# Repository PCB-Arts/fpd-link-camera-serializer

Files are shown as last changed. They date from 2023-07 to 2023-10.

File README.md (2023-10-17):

# fpd-link-camera-serializer
CSI to FDP link serializer board based on the Texas instruments DS90UB953 up to 2.3MP/60fps. Power over coax implementation at 24V cable supply. The board has different I2C sensors to interface with over the I2C - FPD Link Channel. The different sensors are described in the I2C-Sensor section 

## I2C Sensors

### Accelerometer (0x19)
There is a 6-axis Motion Tracking IC installed on the fpd-link-camera-serializer (BMI088). It's purpose is to detecting vibrations or motions. 
Datasheet: https://www.bosch-sensortec.com/media/boschsensortec/downloads/datasheets/bst-bmi088-ds001.pdf

### Gyroscope (0x68)
It's the same BMI088 Chip. 

### Temperature Sensor (0x48) 
There is also a Temperature sensor (TMP1075) installed for detecting envioronment paramenters, which could affect the camera sensor. 
Datasheet: https://www.ti.com/lit/ds/symlink/tmp1075.pdf

### PCA9685 (0x40) 
For interacting with LEDs, for generating local light on the camera side, there is a LED Controller installed (PCA9685). 
Datasheet: https://www.nxp.com/docs/en/data-sheet/PCA9685.pdf

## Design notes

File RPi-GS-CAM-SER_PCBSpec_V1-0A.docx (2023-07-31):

# Document History

Revision | Date / Datum | Short mark | Concerned clause / Betr. Abschnitt | Reason of modification / Grund der Änderung
A | 2023-05-29 | MW | All | First Version

Product: Produkt: | RPi-GS-CAM-SER | Version: | 1.0

Size / Format: | Base dimensions / Grundmass: 38.0 mm x 38.0 mm Tolerances / Toleranzen: Width / Breite 38.0 ± 0.2 mm Length / Länge 38.0 ± 0.2 mm
Thickness / Dicke: | Tolerance / Toleranz: 1.6 mm ± 0.16 mm
Number of layers / Anzahl der Lagen: | 4, plated-through / durchkontaktiert

Build-up of layers / Lagenaufbau: | Material: FR4, UL 94-V0, Gruppe IIIa, 130°C see Build-up of layers (End of Document) siehe Lagenaufbau (Ende des Dokuments)

Number of holes (total) / Anzahl der Bohrungen (gesamt): | 484 (incl. 465 Vias)
Minimum plated through hole diameter / Kleinster Enddurchmesser: | 0.2 mm
Finished plated hole tolerance (deviant from standard) / Bohrtoleranz (abweichend vom Standard): | n/a
Non plated through holes (NDK) / Nicht durchkontaktierte Bohrungen (NDK): | Yes / Ja
SMD: | Double-sided / zweiseitig
Smallest conductor width / Kleinste Leiterbahnbreite: | 0.127 mm
Smallest spacing width / Kleinster Leiterbahnabstand: | 0.15 mm
Gilding of connectors / Steckervergoldung: | No / Nein
Plated through holes to be plugged using Peterslack or equivalent / Durchsteiger mit Peterslack verschließen: | No / Nein
Filling of microvias / Microvias verfüllen: | n/a
Reference point (origin) / Referenzpunkt: | see drawings / siehe Zeichnungen: x 4.0 mm / y 4.0 mm
Order of layers / Lagenfolge: | see file / siehe Datei: RPi-GS-CAM-SER_PCBLayerSpec_ V1-0.pdf
Finish of top and bottom copper surfaces / Metalloberfläche: | Immersion Nickel Gold (PB free) / Chemisch Nickel Gold (Bleifrei)
Electrical conductivity and isolation test / Elektrischer Test: | Yes

Via Type | Layers / Lagen | Pad∅ | Finished∅ Drilling/ Enddurchmesser | Count / Anzahl
Thru vias layers | 1-4 | 0.5 mm | 0.2 mm | 465

Markings and identification / Beschriftungen: | See drawings / siehe Zeichnungen
Other requirements / Weitere Anmerkungen: | - Soldermask: double-sided Lötstopplack: beidseitig - Silkscreen: Yes (Top Overlay / Bottom Overlay) Bestückungsdruck: Ja - Impedanzkontrollierte Leitungen: Impedance controlled traces: Diff. 100 Ohm: L1/L4: 127 µm / 200 µm / 127 µm Single 50 Ohm: L1/L4: 157 µm - Via Tenting: not strictly necessary (restring covered, sleeve free) Abdeckung von Durchkontaktierungen: nicht zwingend notwendig (Restring bedeckt, Hülse frei)

Drawing:

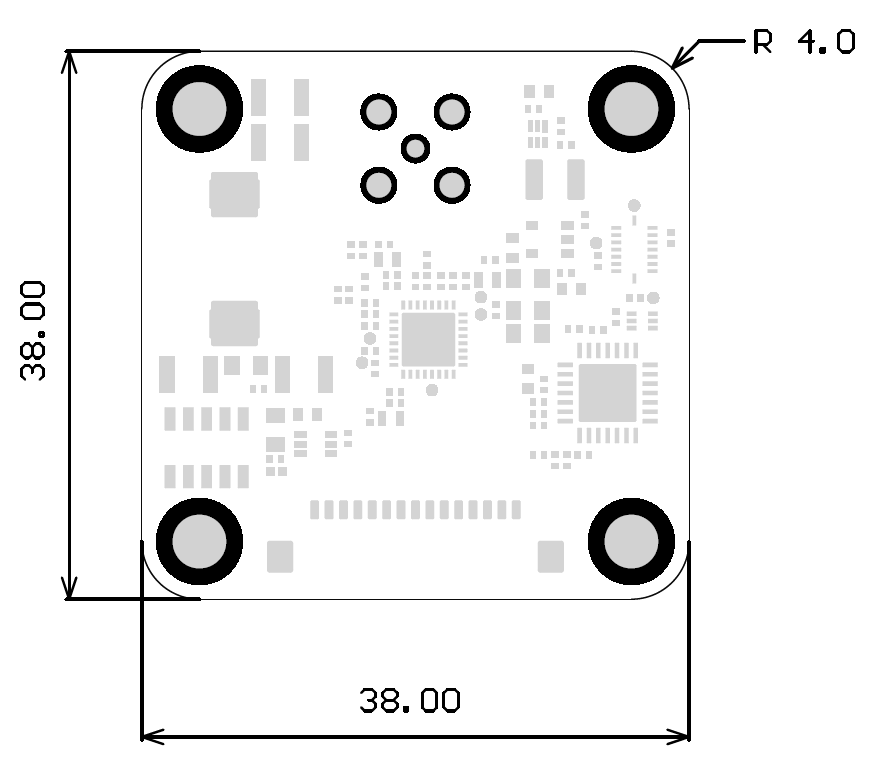
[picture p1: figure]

Figure 1: PCB Dimensions

UL-Marking:

The following information shall be placed on the PCB Bottom Side (see Figure 3):

- PCB Manufacturer Logo
- UL-Marking
- UL-File-No.

Top (Reference Point):

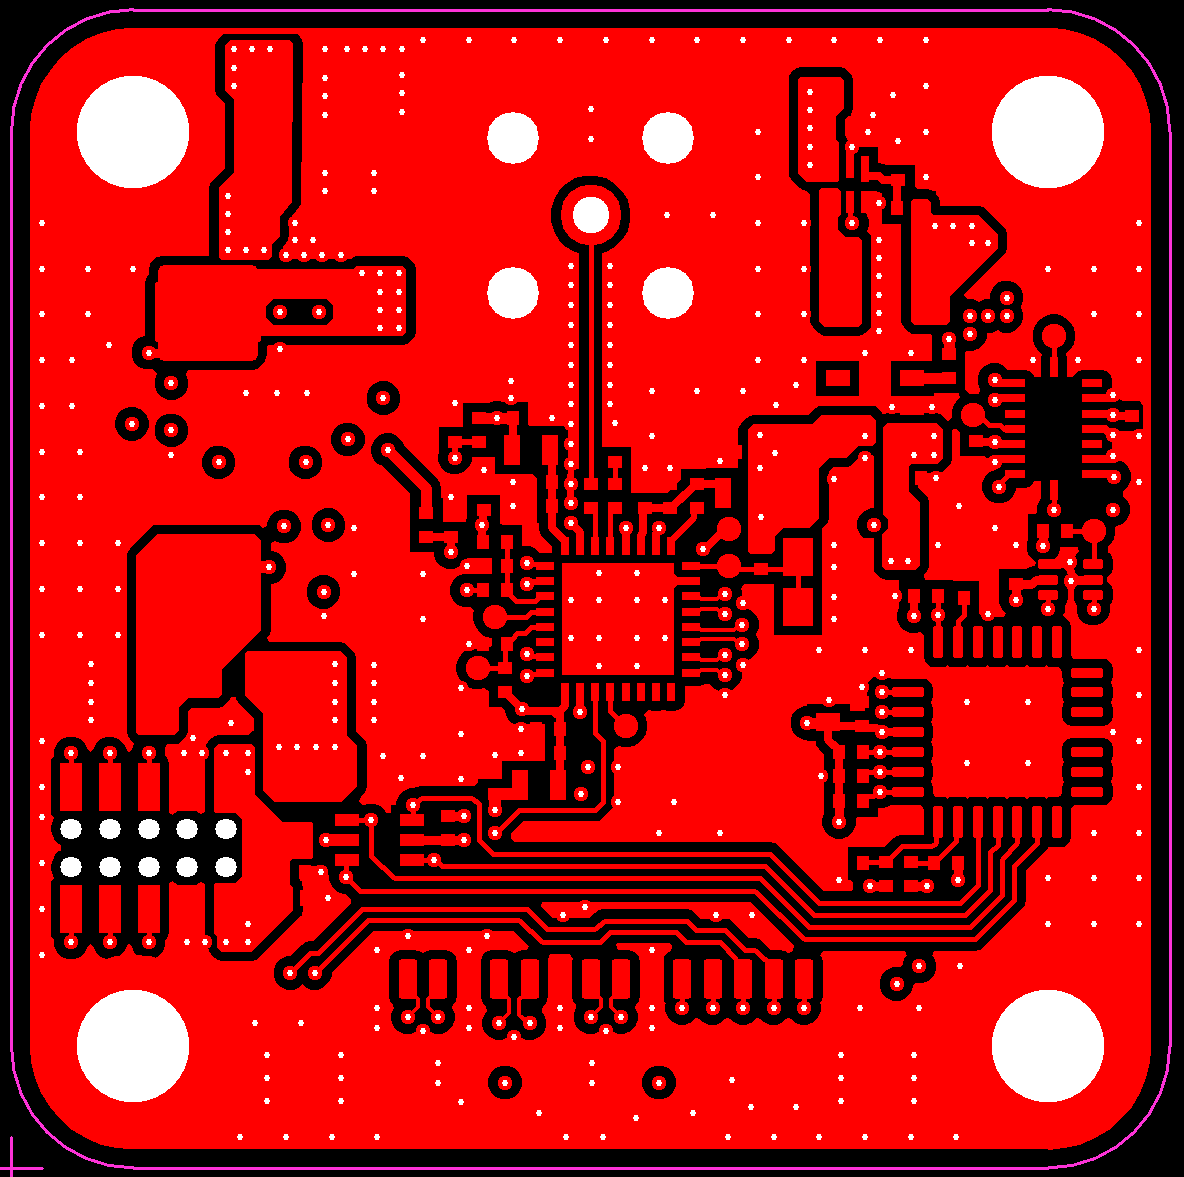
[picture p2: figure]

x: 4.0mm y: 4.0mm

Figure 2: PCB Top Side

Bottom (UL Marking):

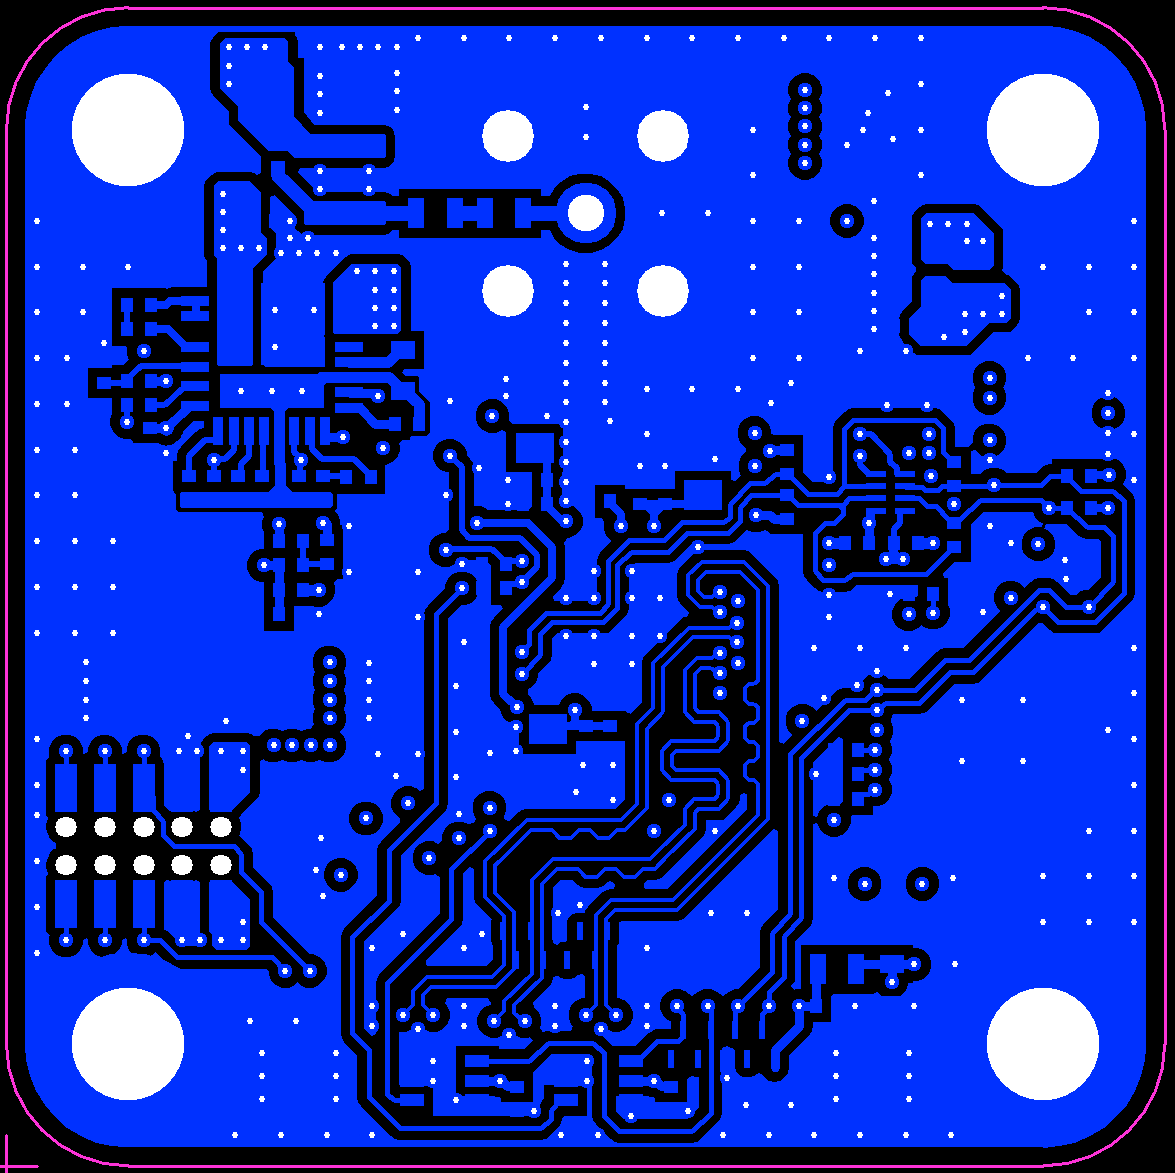
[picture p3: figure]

UL

Figure 3: PCB Bottom Side

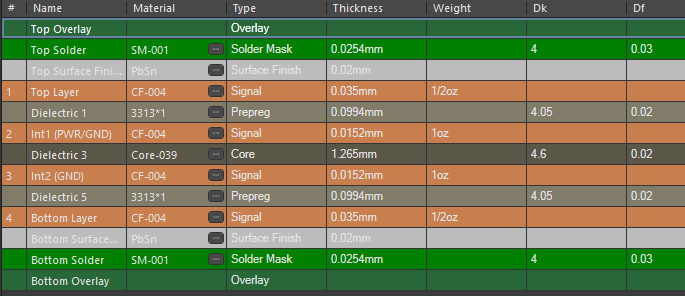
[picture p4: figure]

Figure 4: Build-up of layers

Author: M. Weimann Date: 2023-05-29 File-Name: RPi-GS-CAM-SER_PCBSpec_V1-0A.docx Revision: A

PCB Arts GmbH Kurgartenstraße 59 D-90762 Fürth Phone: +49 170 8512642 Product Specification Printed Circuit Board

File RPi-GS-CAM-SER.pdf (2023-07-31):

Bill of Materials | Bill of Materials for Project [RPi-GS-CAM-SER_V1-0.PrjPcb] (No PCB Document Selected)
Source Data From: | | RPi-GS-CAM-SER_V1-0.PrjPcb
Project: | | RPi-GS-CAM-SER_V1-0.PrjPcb
Variant: | | None
Report Date: | 28.05.2023 | 08:25
Print Date: | 17-Jun-23 | 9:13:52 PM
1 | Documents / PCB Data
# | Document / Data | Details | Value

1 | Schematics | RPi-GS-CAM-SER_SCH_V1-0.PDF | PCB
2 3 | Assembly Drawing | RPi-GS-CAM-SER_ASS_V1-0.PDF | PCB
| Layer Drawings | RPi-GS-CAM-SER_PCB_V1-0.PDF | PCB
4 5 | PCB Dimensions | RPi-GS-CAM-SER_DIM_V1-0.PDF | PCB
| PCB Specification | RPi-GS-CAM-SER_PCBSpec_V1-0.PDF | PCB
6 7 | PCB Layer Specification | RPi-GS-CAM-SER_PCBLayerSpec_V1-0.PDF | PCB
| Gerber Data, NC Drill, Pick & Place | - Gerber - NC Drill - ODB++ - Pick & Place | PCB
8 | Test Specification | n / a | PCBA
2 | Programming Files
# | Name | Filename | Version

1 | n/a
3 | Printed Circuit Board (PCB)
# | Name | Details | | | | | | | | Quantity

1 | RPi-GS-CAM-SER_V1-0 | see PCB Specification and PCB Layer Specifikation | | | | | | | | 1
4 | SMT / THT Components
# | Comment | Description | Designator | Footprint | Library Name | Manufacturer 1 | Manufacturer 1 Prt. Nr. | Manufacturer 2 | Manufacturer 2 Prt. Nr. | Quantity

1 | 1µF 16V | Multilayer Ceramic Capacitors MLCC - SMD/SMT 0402 16VDC | C101, C104, C108, C409 | CAP_0402_L | Cap.SchLib | Taiyo Yuden | EMK105BJ105MVHF | Murata Electronics | GRM155R61E105KA12D | 4
2 3 | 1µF 16V | Multilayer Ceramic Capacitors MLCC - SMD/SMT 0603 16VDC 1uF 10% X7R 0.8mm | C304, C306, C419, C421 | CAP_0603_L | Cap.SchLib | TDK | C1608X7R1C105K080AC | KEMET | C0603C105K4RACTU | 4
| 4.7µF 10V | Multilayer Ceramic Capacitors MLCC - SMD/SMT 4.7 uF 10 VDC 10% 0603 X7R | C410, C414 | CAP_0603_L | Cap.SchLib | Murata Electronics | GRM188Z71A475KE15D | FH (Guangdong Fenghua Advanced Tech) | 0603B475K100NT | 2
4 5 | 4.7µF 50V | Multilayer Ceramic Capacitors MLCC - SMD/SMT 4.7 uF 50 VDC 10% 1206 X7R | C300 | CAP_1206 | Cap.SchLib | Murata Electronics | GRM31CR71H475KA12L | Kemet | C1206X475K5RACAUTO | 1
| 4.7nF 50V | Multilayer Ceramic Capacitors MLCC - SMD/SMT 50V 0.022uF X7R 0402 10% | C405, C412 | CAP_0402_L | Cap.SchLib | Murata Electronics | GCM155R71H472KA37J | KEMET | C0402C472K5RAC7411 | 2
6 7 | 10µF 6.3V | Multilayer Ceramic Capacitors MLCC - SMD/SMT 10 uF 6.3 VDC 10% 0805 X7R | C111, C114, C120, C124 | CAP_0805 | Cap.SchLib | Murata Electronics | GRM21BR70J106KA73L | TDK | CGA4J1X7R0J106K125AC | 4
| 10µF 6.3V | Multilayer Ceramic Capacitors MLCC - SMD/SMT 0603 6.3VDC | C205, C416, C417 | CAP_0603_L | Cap.SchLib | Murata Electronics | GRM188R60J106ME84J | Taiyo Yuden | JMK107ABJ106MA-T | 3
8 9 | 10µF 16V | Multilayer Ceramic Capacitors MLCC - SMD/SMT 16V 10uF X7R 0805 10% | C422 | CAP_0805 | Cap.SchLib | KYOCERA AVX | 0805YC106KAT2A | Samsung Electro-Mechanics | CL21B106KOQNNNG | 1
| 10µF 50V | Multilayer Ceramic Capacitors MLCC - SMD/SMT 10 uF 50 VDC 10% 1210 X7R | C401, C402 | CAP_1210 | Cap.SchLib | Murata Electronics | GRJ32ER71H106KE11L | KEMET | C1210C106K5RACTU | 2
10 11 | 10nF 50V | Multilayer Ceramic Capacitors MLCC - SMD/SMT 0402 50VDC | C102, C105, C109, C113, C116, C122, C204 | CAP_0402_L | Cap.SchLib | Wurth Elektronik | 885012205067 | Yageo | AC0402KPX7R9BB103 | 7
| 15nF 50V | Multilayer Ceramic Capacitors MLCC - SMD/SMT 0402 50VDC | C110 | CAP_0402_L | Cap.SchLib | Murata | GRM155R71H153KA12J | Yageo | CC0402KRX7R9BB153 | 1
12 13 | 22nF 50V | Multilayer Ceramic Capacitors MLCC - SMD/SMT 0402 50VDC | C119, C404 | CAP_0402_L | Cap.SchLib | Murata | GRT155R71H223KE01D | Walsin | 0402B223K500CT | 2
| 33nF 50V | Multilayer Ceramic Capacitors MLCC - SMD/SMT 0402 50VDC | C106, C411 | CAP_0402_L | Cap.SchLib | Murata | GRT155R71H333KE01D | Yageo | CC0402KRX7R9BB333 | 2
14 15 | 47µF 10V | Multilayer Ceramic Capacitors MLCC - SMD/SMT 47 uF 10 VDC 10% 1210 X7R | C406, C407 | CAP_1210 | Cap.SchLib | Murata Electronics | GRM32ER71A476KE15L | KEMET | C1210C106K8RACTU | 2
| 100nF 50V | Multilayer Ceramic Capacitors MLCC - SMD/SMT 0402 50VDC | C100, C103, C107, C112, C115, C117, C118, C121, C123, C126, C200, C201, C202, C203, C206, C301, C302, C303, C305, C307, C308, C400, C403, C408, C413, C415, C418, C420, C423 | CAP_0402_L | Cap.SchLib | Murata Electronics | GCM155L8EH104KE07D | TDK | UMK105B7104KV-FR | 29
16 17 | 10-Pin SMT Pin Socket 2 Row | Headers & Wire Housings WR-PHD 1.27mm SMT St SMT 10P 2Row H=2.2mm | J302 | 6,2331E+11 | Conn.SchLib | Wurth Elektronik | 623310235321 | | | 1
| FA1-NZSP-PCB-2 | FAKRA GEN 1 PCB Through Hole Straight Plug 50 Ohm Z Key Code | J300 | FA1-NZSP-PCB-2 | Conn.SchLib | Amphenol RF | FA1-NZSP-PCB-2 | | | 1
| | Mount, Right-Angle,, Dual-Sided Contact Style, 15 Circuits | J301 | XF3M(1)-1515-1B | Conn.SchLib | Omron | XF3M(1)-1515-1B | | | 1
18 | XF3M(1)-1515-1B | 1.00mm Pitch RotaryBackLock FFC/FPC Connector, Surface
Altium Limited Confidential | 17.06.2023 | Page 1

19 | BMI088 | IMUs - High Performance Intertial Measurement Unit (IMU)
for Drones and Robotics LGA16 4,5 mm x 3,0 mm
U201 | LGA50P450X300X100-
16N
Digital.SchLib | Bosch Sensortec | BMI088 | 1
20 21 | DS90UB953TRHB-Q1 | Serialisierer & Deserialisierer - Serdes 2 MP MIPI CSI-2 FPD-Link III serializer for 2MP/60fps cameras & radar 32-VQFN -40 to 105 | U100 | VQFN50P500X500X100-33N | Digital.SchLib | Texas Instruments | DS90UB953TRHBTQ1 | | | 1
| PCA9685BS | LED-Anzeigetreiber 16-CH 12-BIT PWM FM+ I2C-BUS LED CTRL HVQFN28 6 mm x 6 mm | U203 | QFN65P600X600X100_H S-29N | Digital.SchLib | NXP | PCA9685BS, 118 | | | 1
22 23 | SN74AUP1T97DCKR | Translation - Single-Supply Voltage-level Translator With Nine Configurable Gate Logic Functions | U300, U301 | SOT65P210X100-6N | Digital.SchLib | Texas Instruments | SN74AUP1T97DCKR | | | 2
| TMP1075NDRLR | Board Mount I2C Temperature Sensors with performance upgrades to industry standard LM75 / TMP75 SOT563 1,6 mm x 1,6 mm | U202 | SOT50P160X60-6N_SOT563 | Digital.SchLib | Texas Instruments | TMP1075NDRLR | | | 1
24 25 | 9774100151R | Würth Standoff M2.5 h:10mm 9774050151R | H400, H401, H402, H403 | 9774100151R | Electro_Mech.SchLib | Würth Elektronik | 9774100151R | | | 4
| 742792031 | Ferrite Beads WE-CBF 0805 200MHz 300Ohm 3000mA AEC-Q200 | L304, L402 | L_0805 | Indc.SchLib | Wurth Elektronik | 742792031 | | | 2
26 27 | 742792641 | Ferrite Beads WE-CBF 0603 100MHz 300Ohm 2000mA AEC-Q200 | L404 | L_0603 | Indc.SchLib | Wurth Elektronik | 742792641 | | | 1
| 742863147 | Ferrite Beads WE-CBF HF 0603 SMD 100MHz 470Ohm 500mA | L300, L301 | L_0603 | Indc.SchLib | Wurth Elektronik | 742863147 | | | 2
28 29 | 74479299210 | Fixed Power Inductor - SMD WE-PMCI 1210 1.0uH 3A 38mOhms 30%Tol | L403 | WE-PMCI_1210 | Indc.SchLib | Wurth Elektronik | 74479299210 | | | 1
| BLM18AG102SN1D | Ferrite Beads BLM18 1000Ohms 450mA 0,5Ohm | L100, L101, L102, L303 | L_0603 | Indc.SchLib | Murata Electronics | BLM18AG102SN1D | | | 4
30 31 | IHLP4040DZER150M11 | 15uH ±20% 6A 45mΩ SMD,10.16x10.16x4mm Power Inductor | L401 | IHLP-4040DZ-11 | Indc.SchLib | Visay Dale | IHLP4040DZER150M11 | | | 1
| LQH3NPN100MJRL | 10uH ±20% 0.8A 240mΩ SMD,3.0x3.0x1.1mm Chip Inductor | L302 | LQH3NPN100MJRL | Indc.SchLib | Murata Electronics | LQH3NPN100MJRL | | | 1
32 33 | LP5907MFX-1.8/NOPB | LDO Spannungs-Regulator 250mA Ultra-Lo Noise LDO Reg SOT23-5 | U402 | SOT95P285X140-5N | Power.SchLib | Texas Instruments | LP5907MFX-1.8/NOPB | | | 1
| SIC463ED-T1-GE3 | Switching Voltage Regulators 4A, 4.5-60V buck reg 100kHZ to 2MHz; 5 mm x 5 mm MLP55-27L package | U400 | VISHAY_MLP55-27L | Power.SchLib | Vishay Siliconix | SIC463ED-T1-GE3 | | | 1
34 35 | TLV62568ADRL | Step Down Converter with Forced PWM in SOT563 Package | U401 | SON50P150X80-6N | Power.SchLib | Texas Instruments | TLV62568ADRL | | | 1
| 82400274 | ESD Suppressors / TVS Diodes WE-TVS High Speed 5uA 5VDC 4+1 | D303 | SOT65P210X100-6N | Protec.SchLib | Wurth Elektronik | 82400274 | | | 1
36 37 | 824014883 | ESD Suppressors / TVS Diodes WE-TVS Diode Array 3.3V 0.5pF 8Channel | D300, D301 | WE-TVS-DFN3810-9L | Protec.SchLib | Wurth Elektronik | 824014883 | | | 2
| CESDP0402UC5VB | Low Capacitance ESD Protection Diode 0402 | D302 | TVS_0402 | Protec.SchLib | CREATEK | CESDP0402UC5VB | BORN | BPESD0402-05ST | 1
38 39 | 0R Jumper | Thick Film Resistors - SMD 0Ohm | R101, R200, R201, R210 | RES_0402_L | Res.SchLib | Vishay / Dale | CRCW04020000Z0EDC | Yageo | RC0402JR-070RL | 4
| 1.2k 1% | Thick Film Resistors - SMD 1/16watt 1.2Kohms 1% | R105 | RES_0402_L | Res.SchLib | Vishay / Dale | CRCW04021K20FKEDC | Yageo | RC0402FR-7W1K2L | 1
40 41 | 2k 1% | Thick Film Resistors - SMD 2 kOhms 62.5mW 0402 1% | R407 | RES_0402_L | Res.SchLib | Vishay / Dale | CRCW04022K00FKEDC | Yageo | RC0402FR-072KL | 1
| 2.2R 1% | Thick Film Resistors - SMD 2.2Ohm 1% | R400 | RES_0402_L | Res.SchLib | Vishay / Dale | CRCW04022R20JNED | Yageo | RC0402FR-7W2R2L | 1
42 43 | 4.02k 1% | Thick Film Resistors - SMD 4.02kOhm 1% | R300, R403 | RES_0402_L | Res.SchLib | Vishay / Dale | CRCW04024K02FKEDC | Yageo | RC0402FR-134K02L | 2
| 4.7k 1% | Thick Film Resistors - SMD 4.7kOhm 1% | R204, R205 | RES_0402_L | Res.SchLib | Vishay / Dale | CRCW04024K70FKEDC | Yageo | RC0402FR-134K7L | 2
44 45 | 10k 1% | Thick Film Resistors - SMD 10kOhm 1% | R106, R108, R206, R213, R214, R215, R216, R217, R218, R219, R410, R413 | RES_0402_L | Res.SchLib | Vishay / Dale | CRCW040210K0FKEDC | Yageo | RC0402FR-7W10KL | 12
| 24k 1% | Thick Film Resistors - SMD 24kOhm 1% | R408 | RES_0402_L | Res.SchLib | Vishay / Dale | CRCW040224K0FKEDC | Yageo | RC0402FR-7W24KL | 1
46 47 | 27k 1% | Thick Film Resistors - SMD 27kOhm 1% | R103 | RES_0402_L | Res.SchLib | Vishay / Dale | CRCW040227K0FKEDC | Yageo | RT0402FRE0727KL | 1
| 49.9k 1% | Thick Film Resistors - SMD 49.9kOhm 1% | R404 | RES_0402_L | Res.SchLib | Vishay / Dale | CRCW040249K9FKEDC | Yageo | RC0402FR-7W49K9L | 1
48 49 | 49.9R 1% | Thick Film Resistors - SMD 49.9Ohm 1% | R100 | RES_0402_L | Res.SchLib | Vishay / Dale | CRCW040249R9FKEDC | Yageo | RC0402FR-7W49R9L | 1
| 52.3k 1% | Thick Film Resistors - SMD 52.3kOhm 1% | R405 | RES_0402_L | Res.SchLib | Vishay / Dale | CRCW040252K3FKEDC | Yageo | RC0402FR-1352K3L | 1
50 51 | 75k 1% | Thick Film Resistors - SMD 75kOhm 1% | R406 | RES_0402_L | Res.SchLib | Vishay / Dale | CRCW040275K0FKEDC | Yageo | AC0402FR-0775KL | 1
| 82.5k 1% | Thick Film Resistors - SMD 1/16W 82.5Kohms 1% | R107 | RES_0402_L | Res.SchLib | Vishay / Dale | CRCW040282k5FKEDC | Bourns | CR0402-FX-8252GLF | 1
52 53 | 100k 1% | Thick Film Resistors - SMD 100kOhm 1% | R402, R412 | RES_0402_L | Res.SchLib | Vishay / Dale | CRCW0402100KFKEDC | Yageo | RC0402FR-7W100KL | 2
| 102k 1% | Thick Film Resistors - SMD 102KOHM 1/16WATT 1% | R109 | RES_0402_L | Res.SchLib | Vishay / Dale | CRCW0402102kFKEDC | Bourns | CR0402-FX-1023GLF | 1
54 55 | 105k 1% | Thick Film Resistors - SMD 105kOhm 1% | R409 | RES_0402_L | Res.SchLib | Vishay / Dale | CRCW0402105KFKEDC | Yageo | RC0402FR-13105KL | 1
| 402R 1% | Thick Film Resistors - SMD 402Ohms 1/16W 0402 1% | R110 | RES_0402_L | Res.SchLib | Vishay / Dale | CRCW0402402RFKEDC | Yageo | RC0402FR-7W402RL | 1
56 57 | 453k 1% | Thick Film Resistors - SMD 1/16watt 453Kohms 1% | R411 | RES_0402_L | Res.SchLib | Vishay / Dale | CRCW0402453KFKED | Bourns | CR0402-FX-4533GLF | 1
| 562k 1% | Thick Film Resistors - SMD 562kOhms 62.5mW 0402 1% | R401 | RES_0402_L | Res.SchLib | Vishay / Dale | CRCW0402562KFKEDC | Yageo | AC0402FR-07562KL | 1

### Approved

58 | 620R 1% | Thick Film Resistors - SMD 1/16watt 620ohms 1% | R102 | RES_0402_L | Res.SchLib | Vishay / Dale | CRCW0402620RFKED | Yageo | RC0402FR-07620RL | 1
59 | 820R 1% | Thick Film Resistors - SMD 1/16watt 820ohms 1% | R104 | RES_0402_L | Res.SchLib | Vishay / Dale | CRCW0402820RFKED | Yageo | RC0402FR-07820RL | 1
Notes | 137

The information contained in these documents is confidential, privileged and only for the information of the intended recipient and may not be used, published or redistributed without
the prior written consent from PCB Arts GmbH.

### PCB Arts GmbH https://pcb-arts.com/ Sitz: Fürth, Bayern Registergericht: Amtsgericht Fürth, HRB 16070 Geschäftsführer: Saber Kaygusuz

Altium Limited Confidential | 17.06.2023 | Page 2

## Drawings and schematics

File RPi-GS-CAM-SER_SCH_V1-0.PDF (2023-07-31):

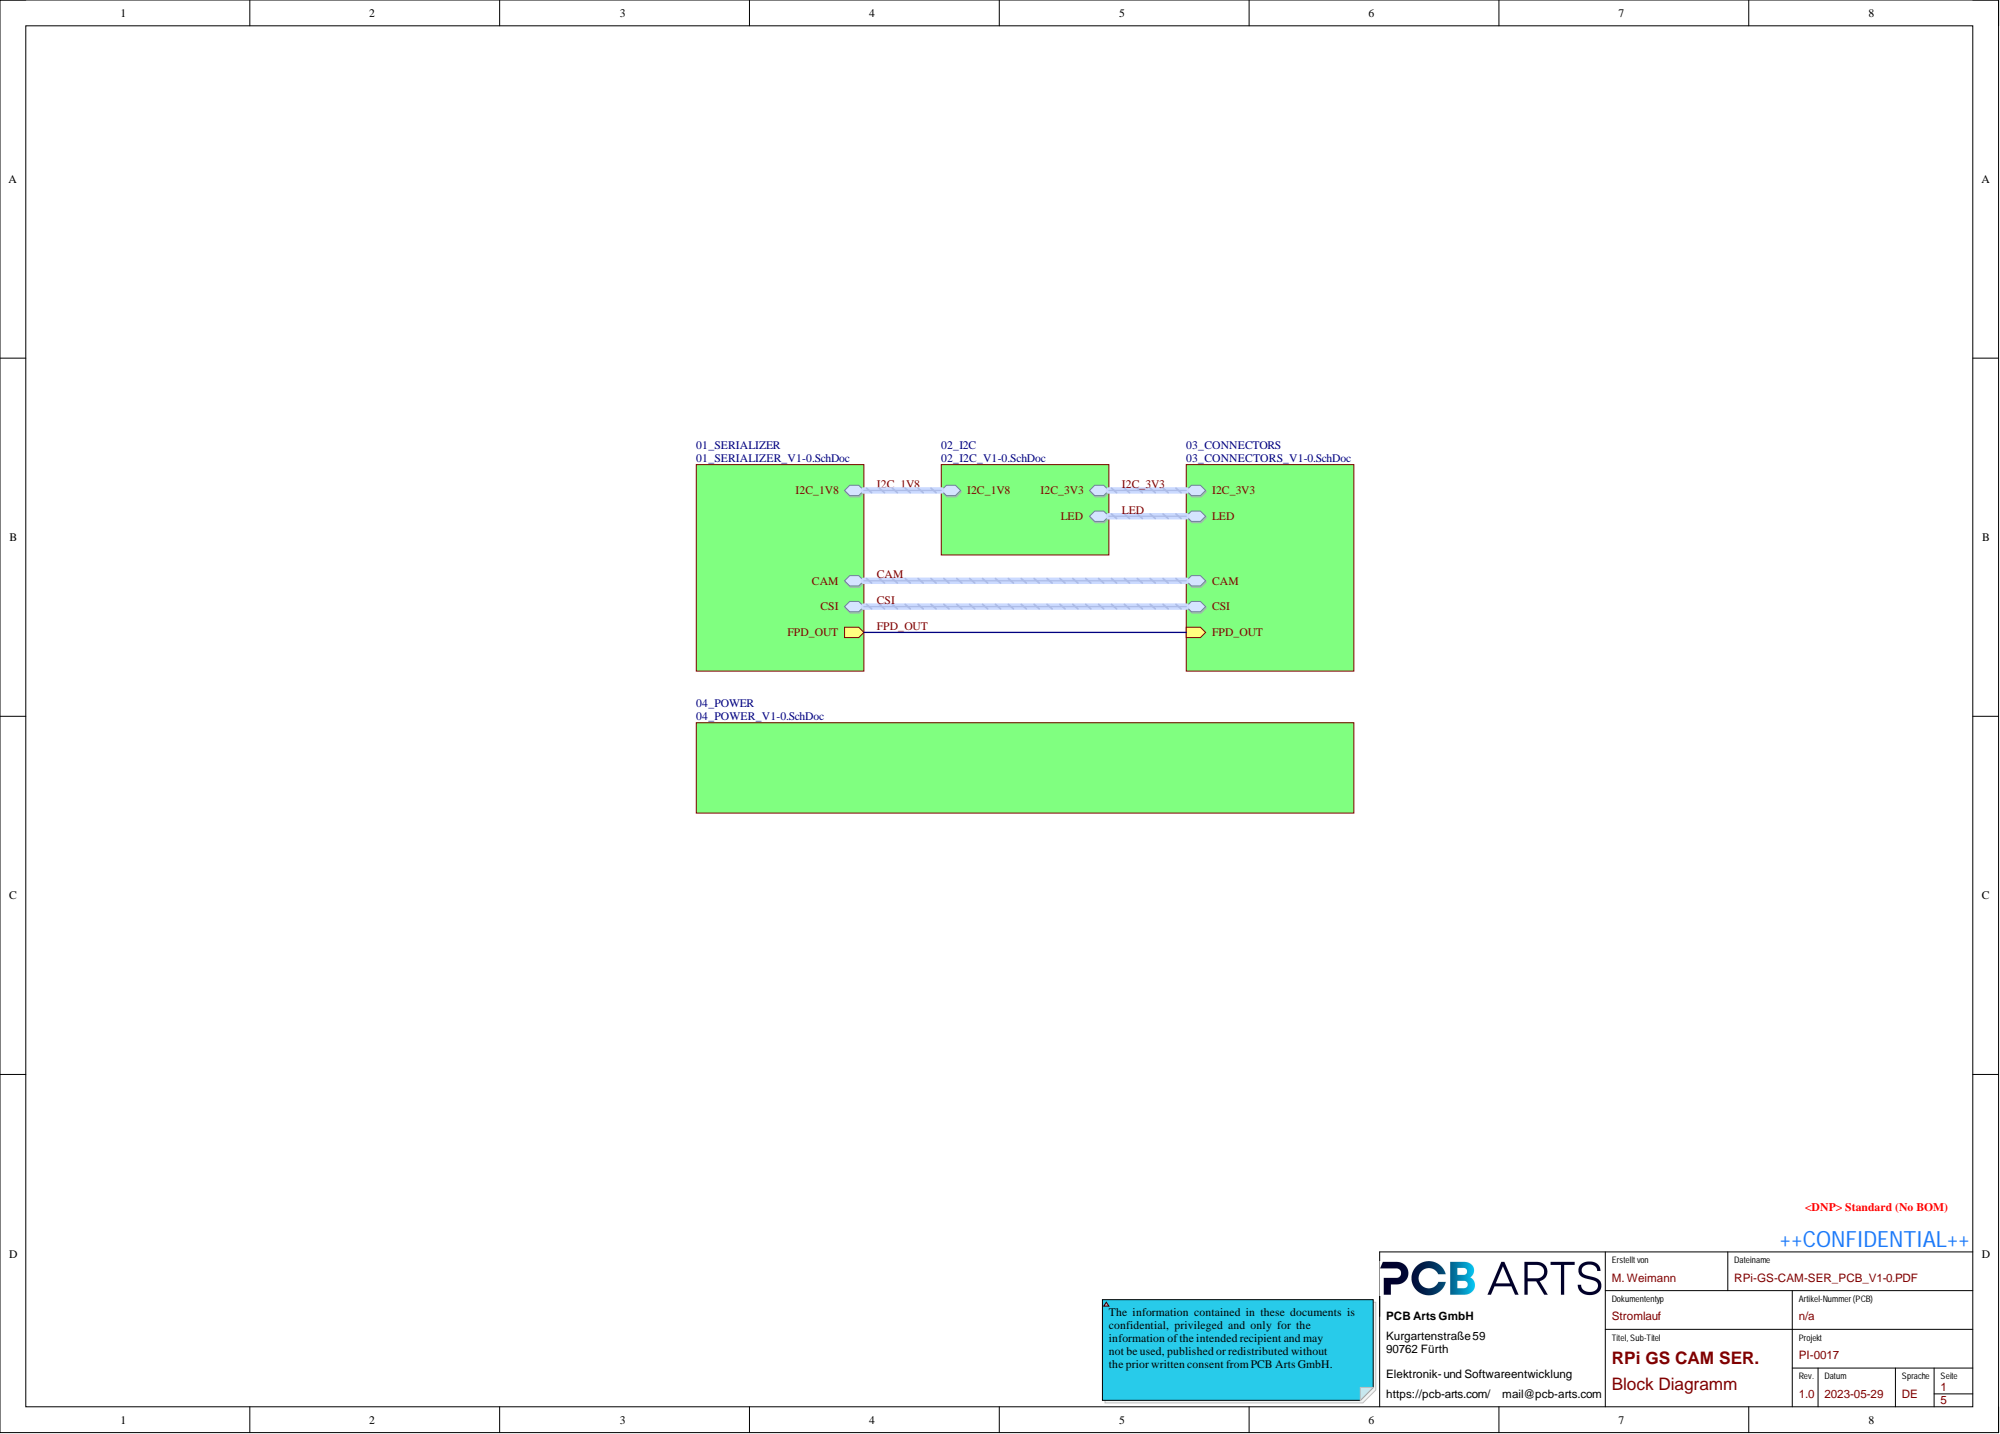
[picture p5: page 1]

<DNP> Standard (No BOM)
++CONFIDENTIAL++

The information contained in these documents is
confidential, privileged and only for the
information of the intended recipient and may
not be used, published or redistributed without
the prior written consent from PCB Arts GmbH.

Titel, Sub-Titel
RPi GS CAM SER.

Elektronik- und Softwareentwicklung
https://pcb-arts.com/ mail@pcb-arts.com

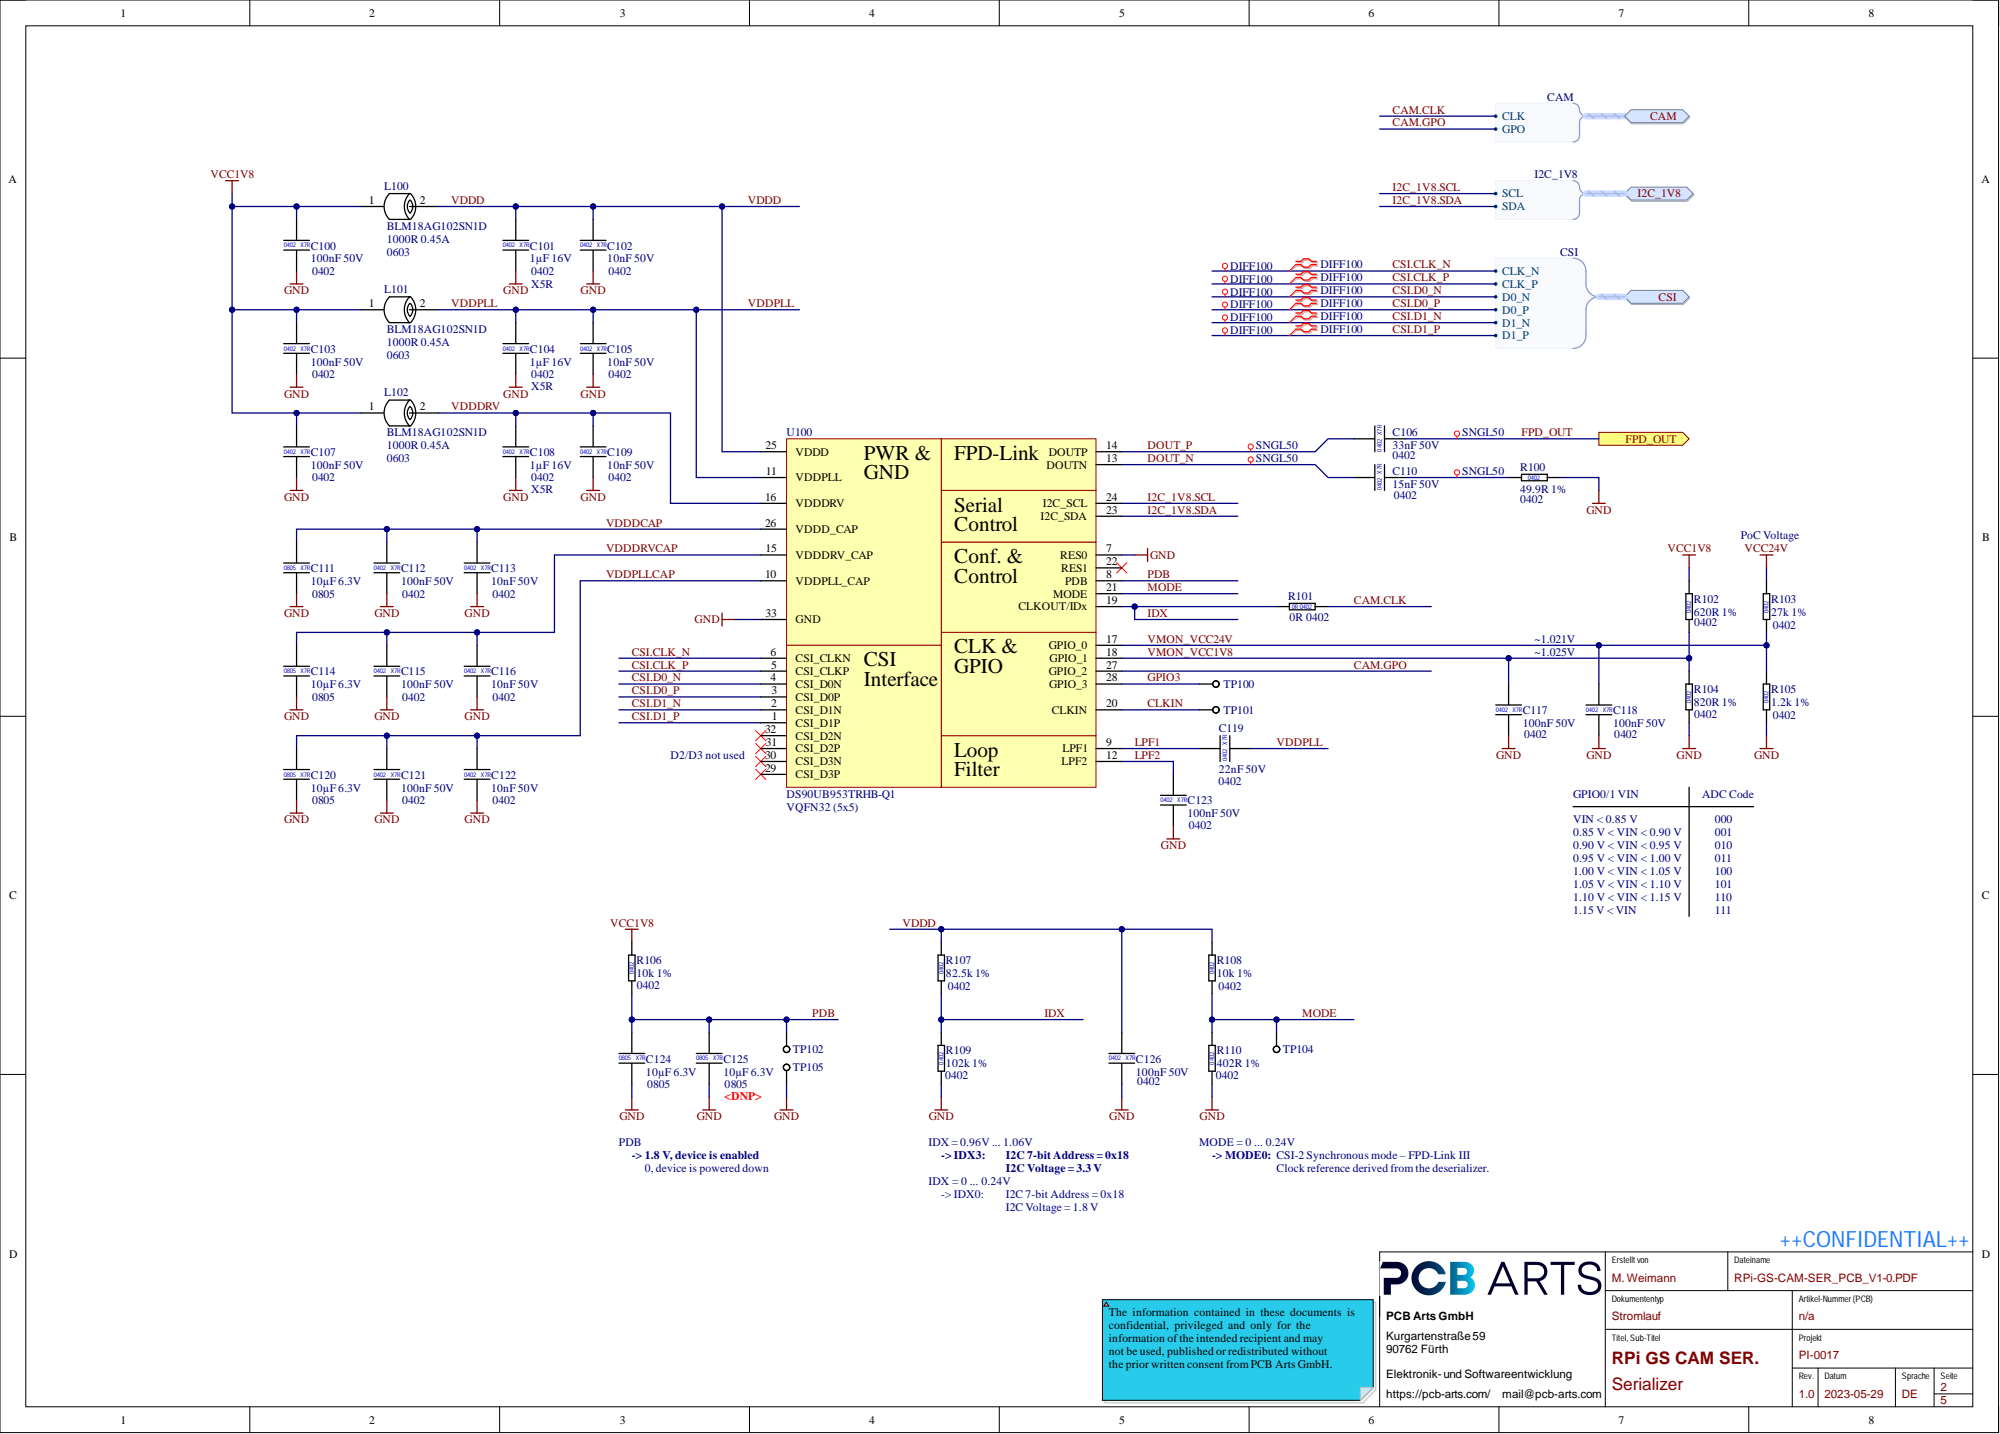
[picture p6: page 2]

CSI_CL KN CSI CSI_CL K P Interfa c e CSI_ D 0 N CSI_ D 0 P CSI_ D 1 N CSI_ D 1 P CSI_ D 2 N CSI_ D 2 P CSI_ D 3 N CSI_ D 3 P | 1 8 | VMO N _ VCC 1 V 8 ~ 1.0 2 5 V

2 7 2 8 GPIO 3

RPi GS CAM SER. Erstellt von

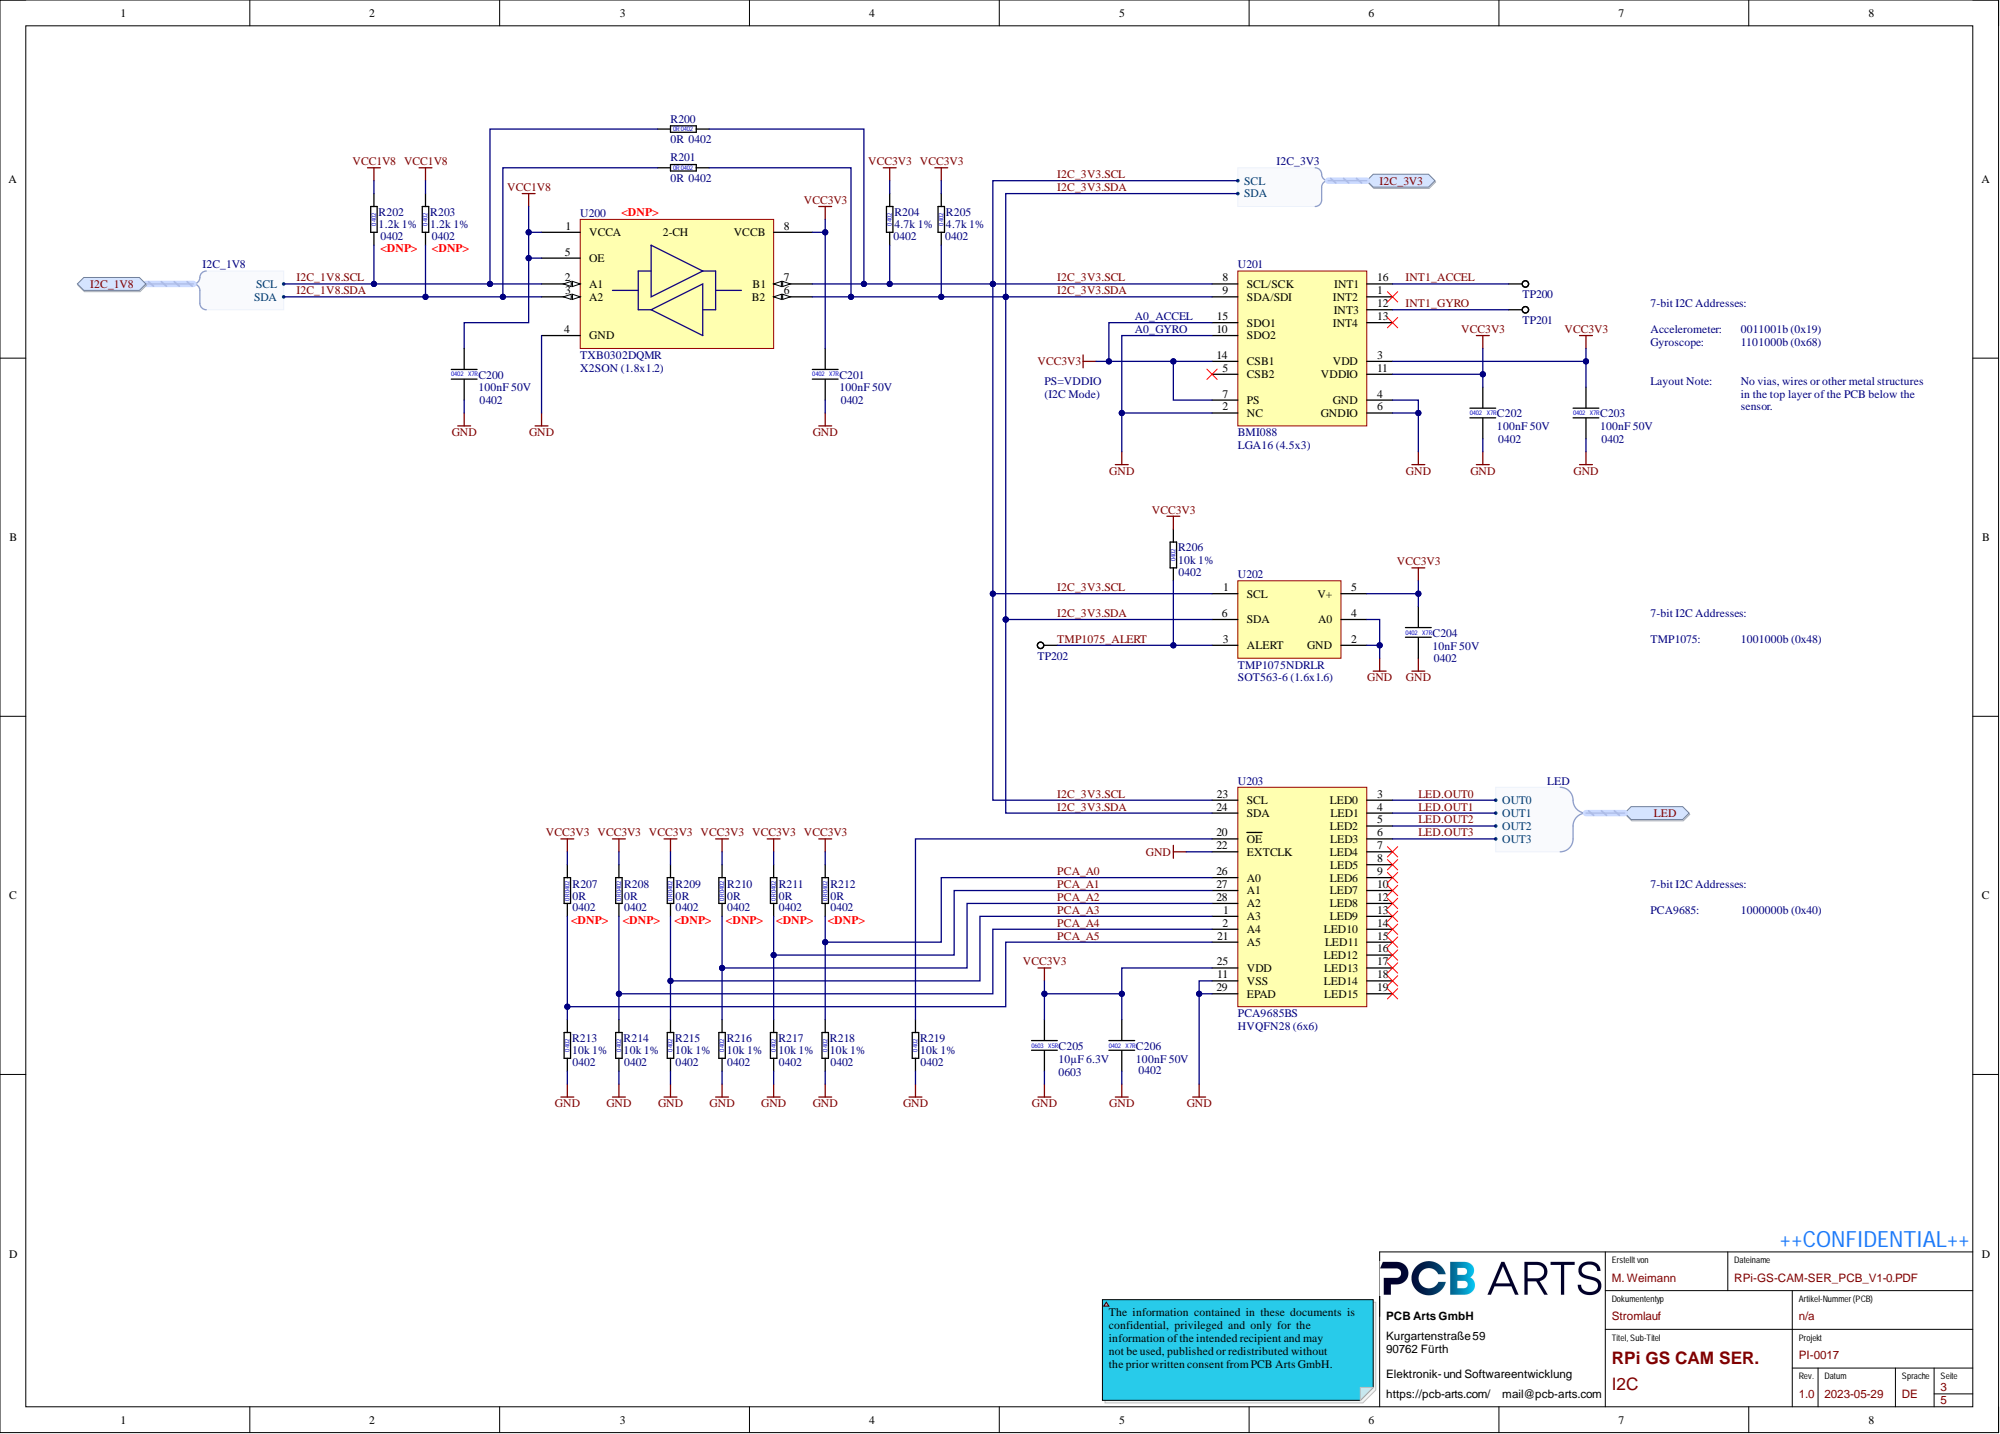
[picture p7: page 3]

VCCA 1

A2 3 GND 4

I2C_3V3.SDA | SDA/SDI 9

A0_ACCEL
A0_GYRO | SDO2 10

CSB1 14

in the top layer of the PCB below the
sensor.

PCA_A0 | | | EXTCLK 22

PCA_A1 | | A1 27
PCA_A2 | | A2 28
PCA_A3 | | A3 1
PCA_A4 PCA_A5 | A4 2

VCC3V3

VDD 25
VSS 11
EPAD 29

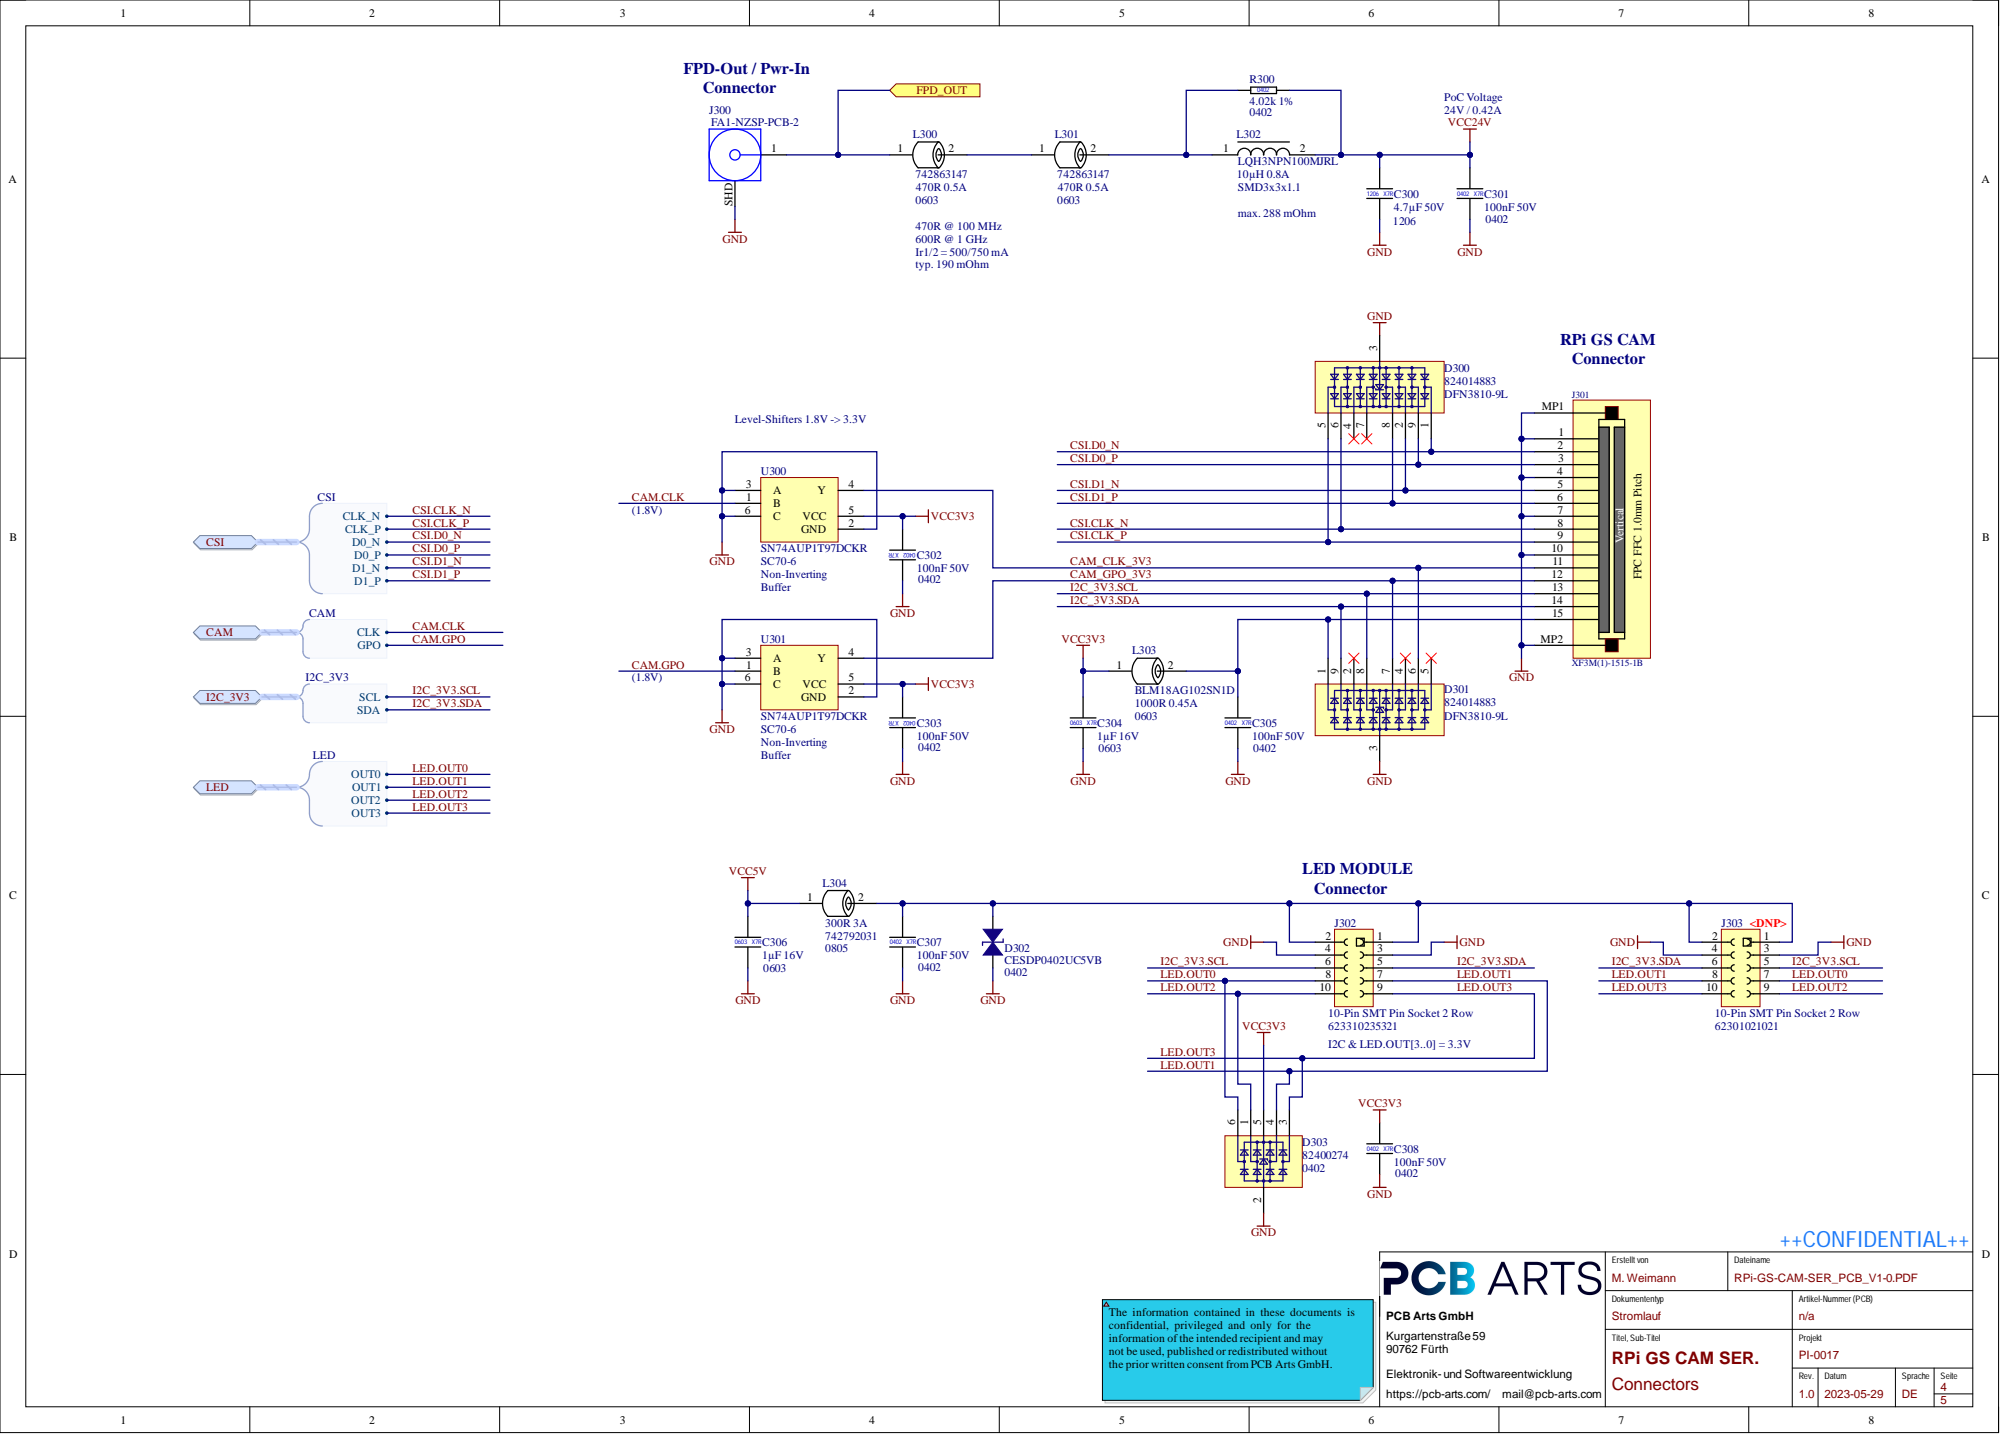
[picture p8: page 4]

FPD-Out / Pwr-In
Connector

2 3 4

100nF 50V 0402 CAM_GPO_3V3 | | 12

LED.OUT2 | 10 | | 9 LED.OUT3

LED.OUT3 | VCC3V3 | 10-Pin SMT Pin Socket 2 Row

10-Pin SMT Pin Socket 2 Row

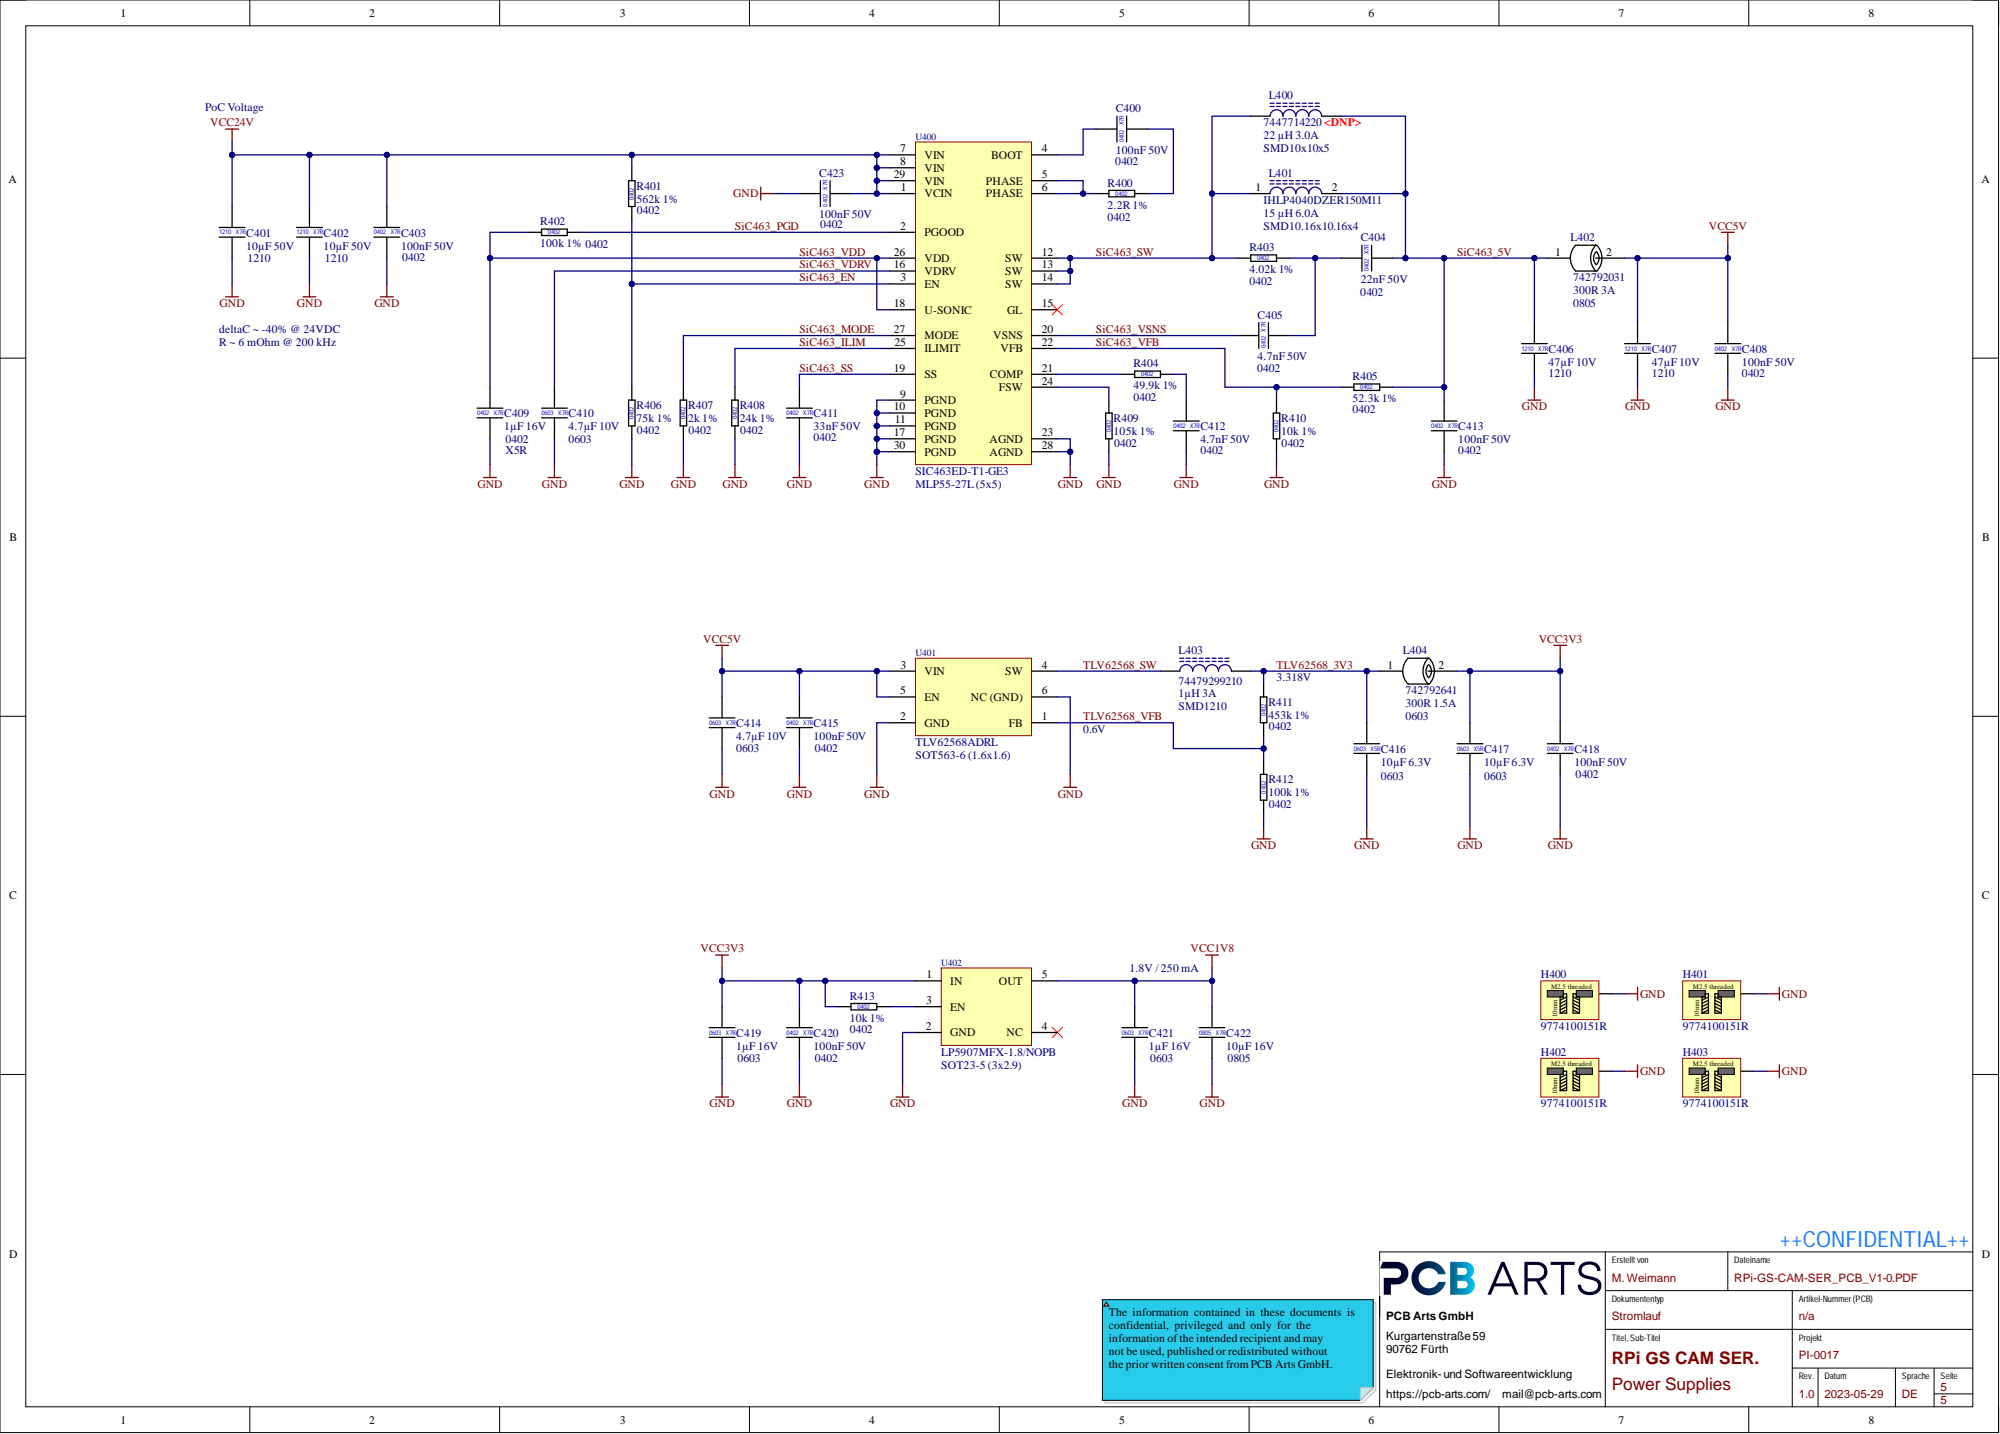
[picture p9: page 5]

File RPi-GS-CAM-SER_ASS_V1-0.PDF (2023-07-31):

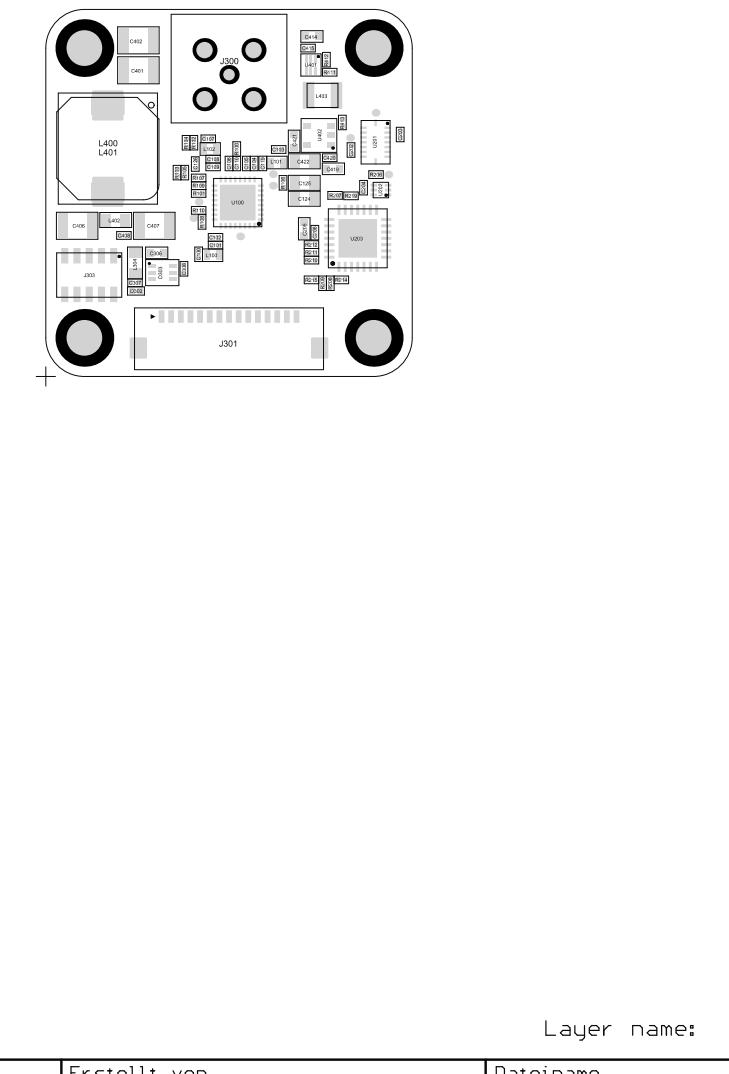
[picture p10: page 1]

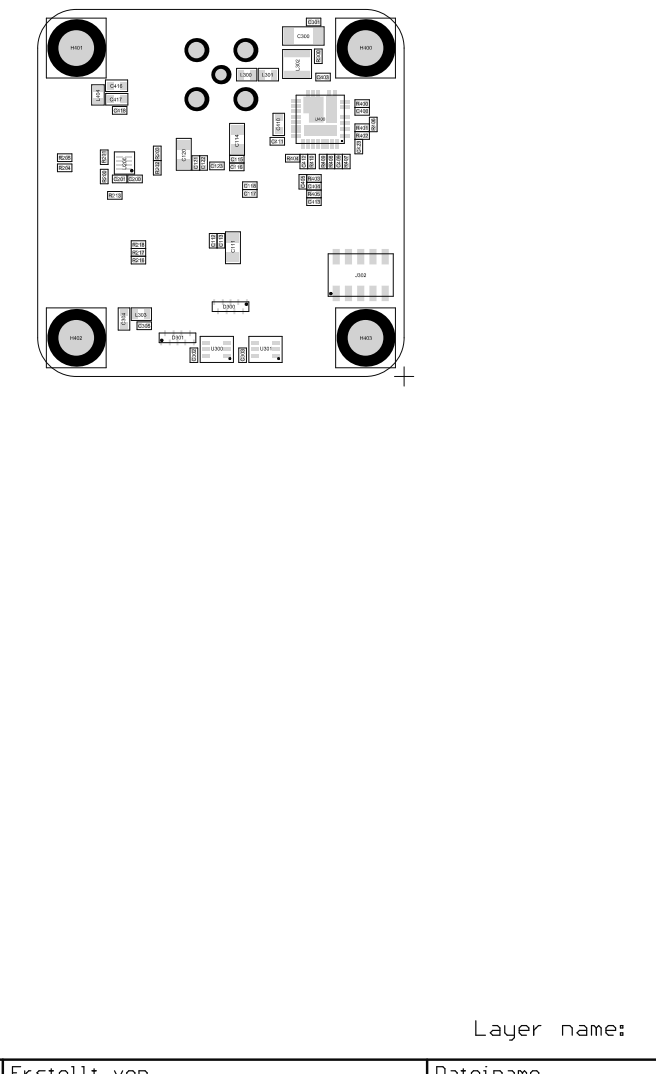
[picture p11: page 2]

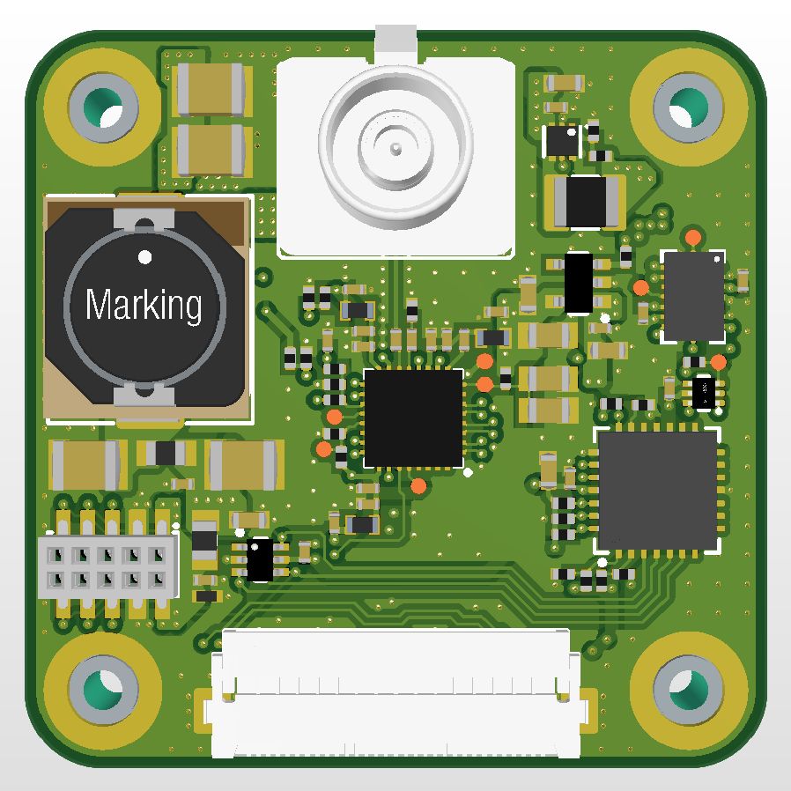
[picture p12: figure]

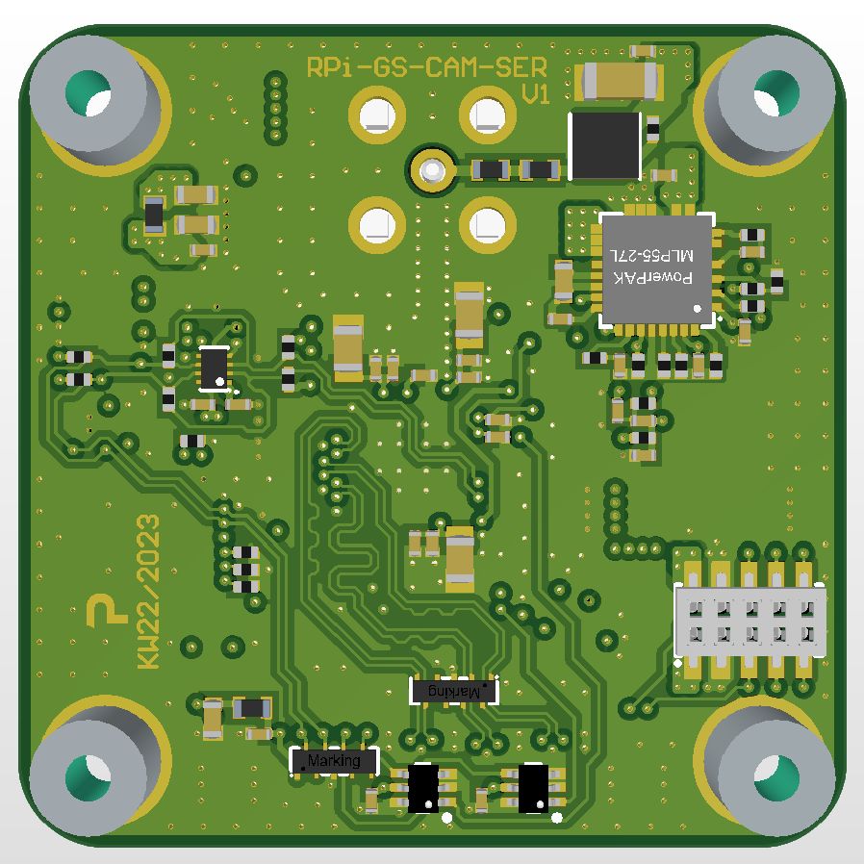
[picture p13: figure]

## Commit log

2023-07-31 Add files via upload
    Initial commit
    [00_RPi-GS-CAM-SER_V1-0.SchDoc, 01_SERIALIZER_V1-0.SchDoc, 02_I2C_V1-0.SchDoc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]
2023-07-31 Add files via upload
    Added schematic, PCB and BOM printout
2023-10-17 Update README.md
    Added I2C Sensors to the README
2023-10-19 Create init_sensors.sh
    Initialized script for i2c sensors - written registers for deserializer "ds90ub960"
